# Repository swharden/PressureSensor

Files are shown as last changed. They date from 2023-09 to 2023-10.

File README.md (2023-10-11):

# Digital Pressure Sensor

This project contains design files for a minimal complexity digital pressure sensor. It uses a [HX710](https://image.micros.com.pl/_dane_techniczne_auto/uphx710b%20smd.pdf) 24-bit ADC to read differential voltage across a Whetstone bridge pressure sensor, then an [AD64DD32](https://ww1.microchip.com/downloads/aemDocuments/documents/MCU08/ProductDocuments/DataSheets/AVR64DD32-28-Prelim-DataSheet-DS40002315B.pdf) applies signal filtering in software and outputs the result as an analog signal using its built-in DAC. Filtering in software allows filter settings and recording modes to be adjusted in real time or further modified using firmware updates. Pressure is displayed on a multiplexed 7-segment display driven directly by pins of the microcontroller. Display mode can be toggled between pressure value, wave period, or wave frequency.

### Version 1.0

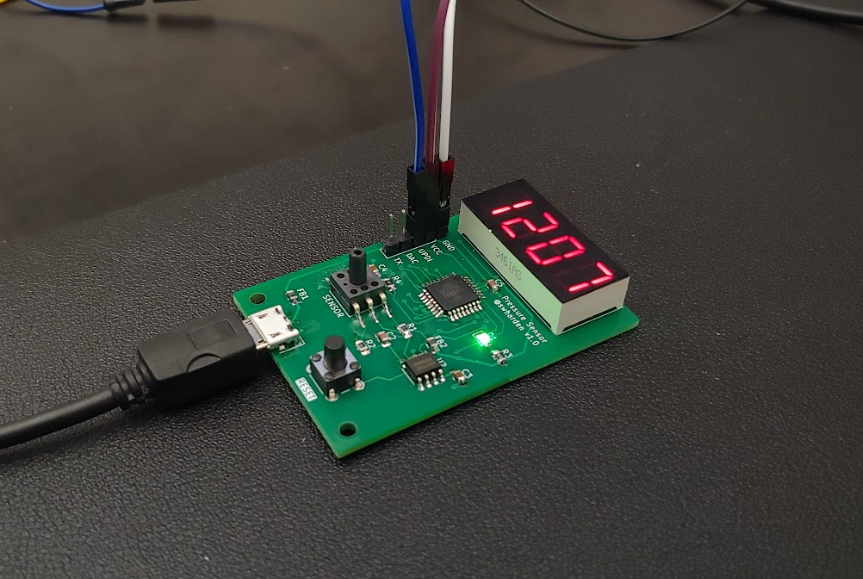
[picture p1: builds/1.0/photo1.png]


### Version 2.0

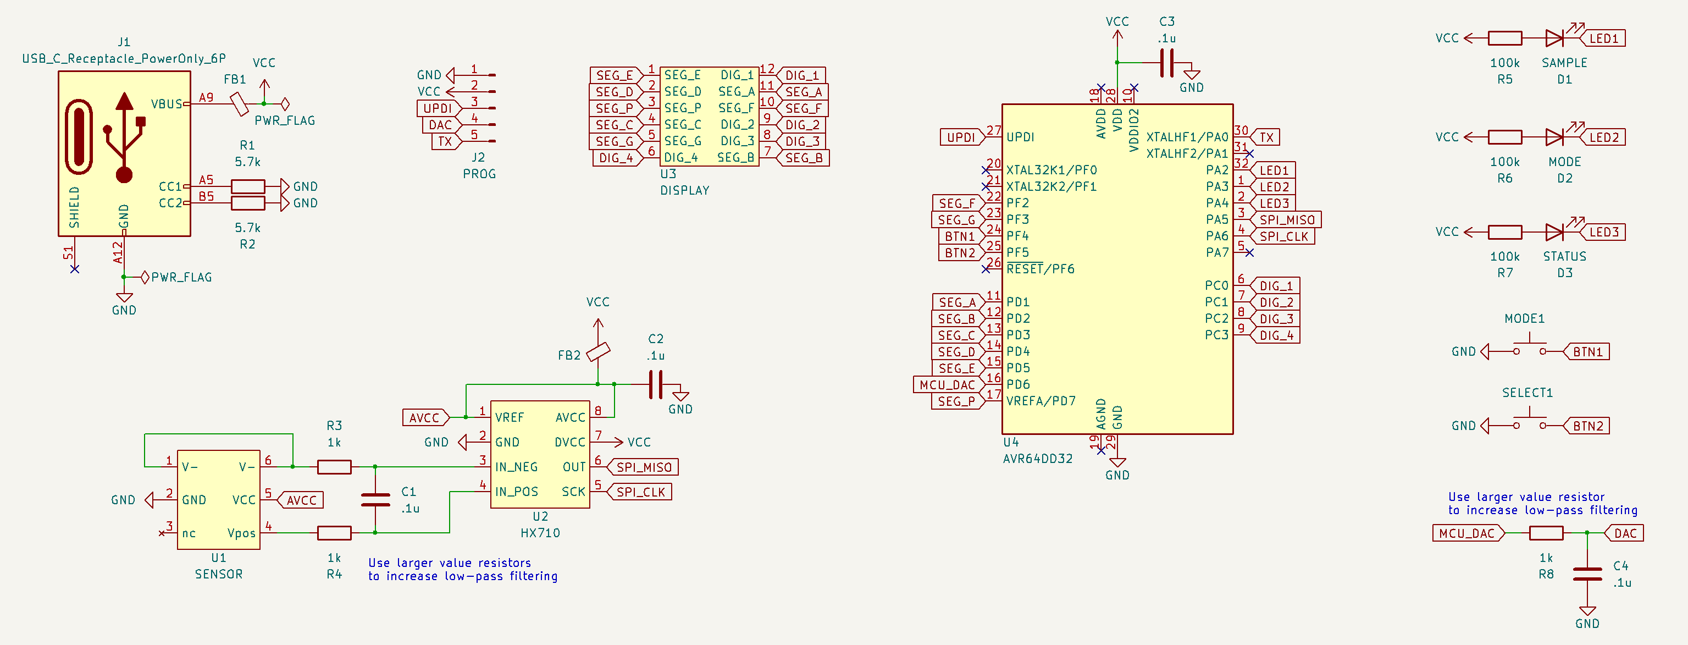
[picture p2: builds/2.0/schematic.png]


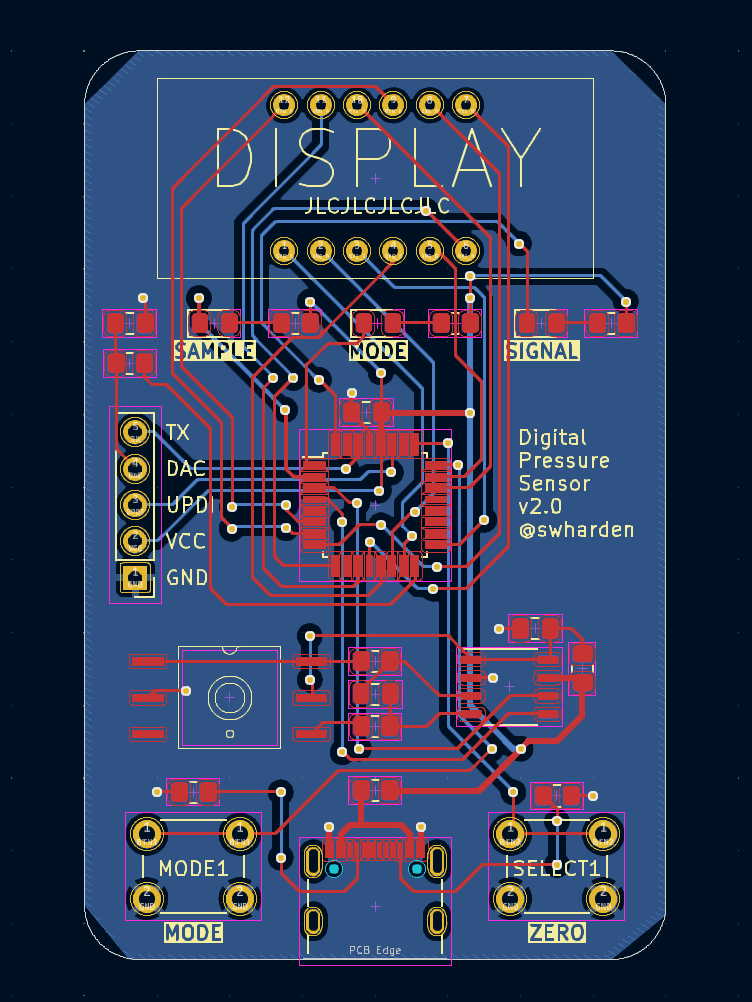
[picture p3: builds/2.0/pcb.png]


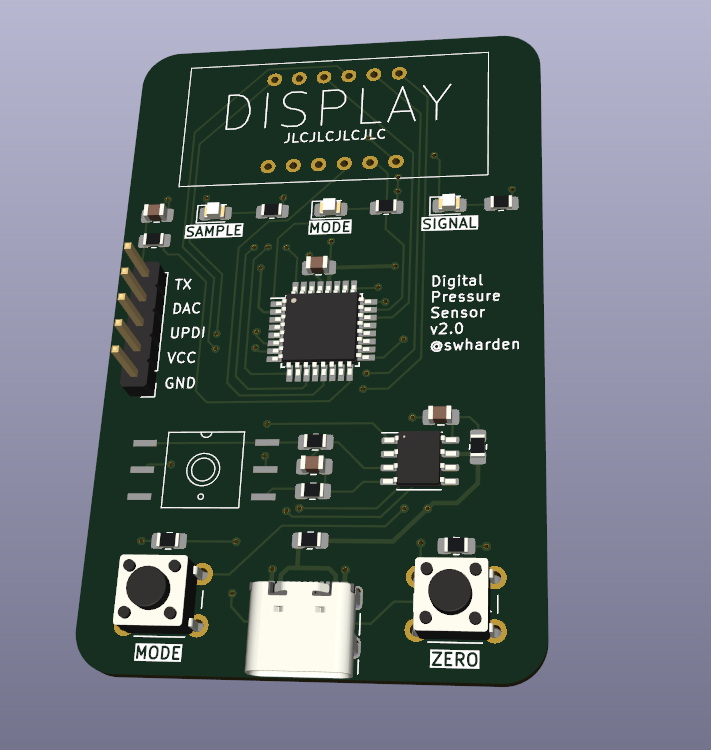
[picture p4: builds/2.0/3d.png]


#### Build Notes

* Through-hole buttons have leads out the bottom which fight against adhesive pads at the corners
* PCB near display could be notched to facilitate string or zip tie mounting vertically
* I'm unsure whether I like the USB connector on the bottom. The whole board could be turned upside down with the connector and buttons on the top.

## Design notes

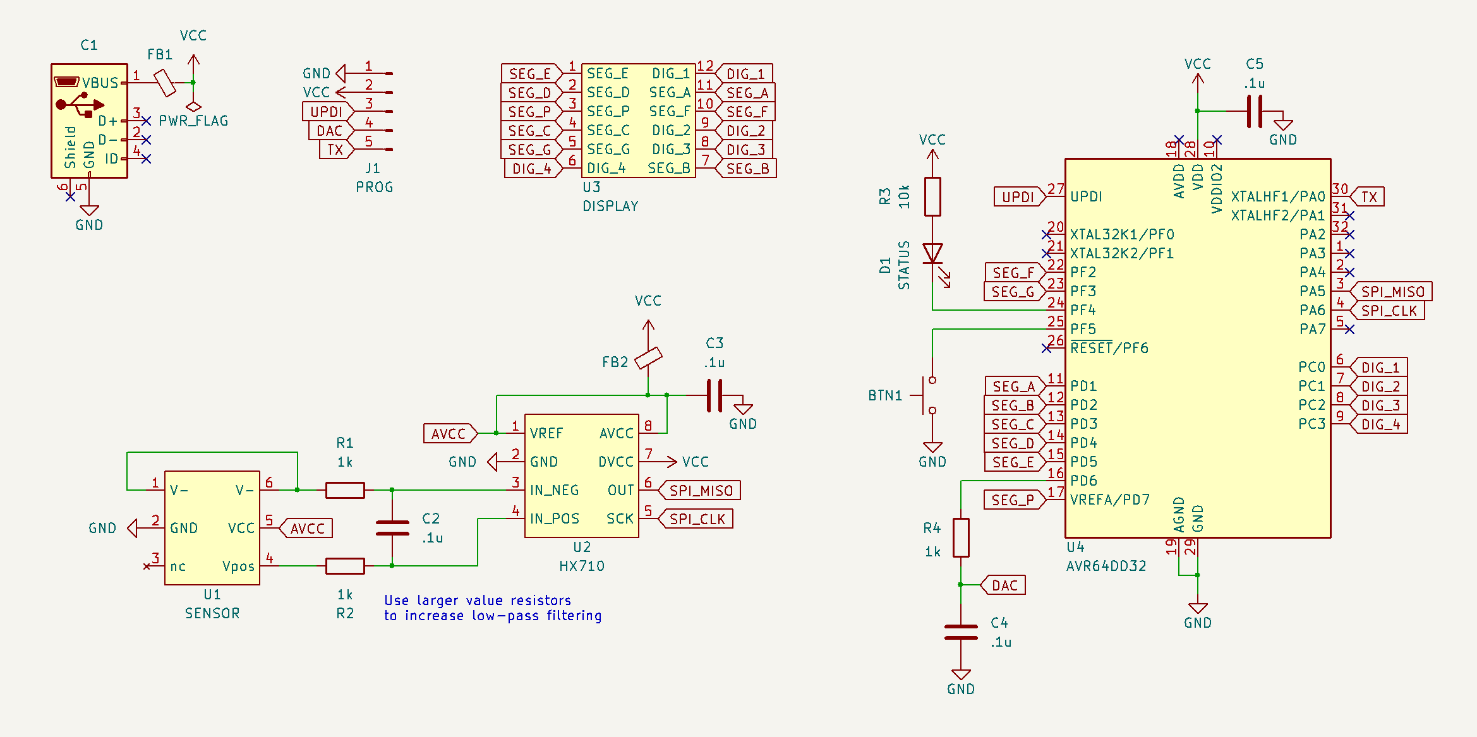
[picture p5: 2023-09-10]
builds/1.0/schematic.png

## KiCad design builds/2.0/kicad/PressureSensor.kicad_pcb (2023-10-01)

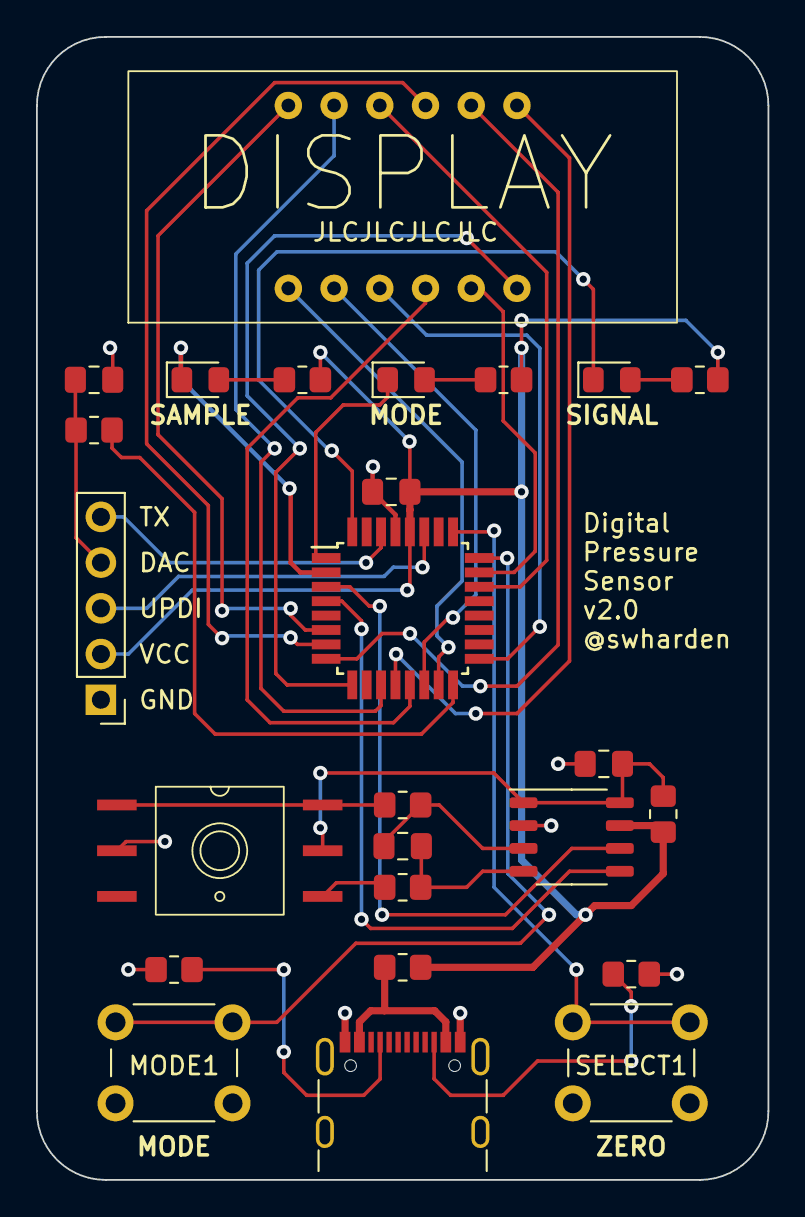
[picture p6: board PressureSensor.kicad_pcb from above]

Board: 2 copper layers, 40.6 x 63.5 mm, 25 parts (0 on the bottom side), 36 nets.

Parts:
C1, C2, C3, C4: .1u; C_0805_2012Metric_Pad1.18x1.45mm_HandSolder
D1: SAMPLE; LED_0805_2012Metric_Pad1.15x1.40mm_HandSolder
D2: MODE; LED_0805_2012Metric_Pad1.15x1.40mm_HandSolder
D3: STATUS; LED_0805_2012Metric_Pad1.15x1.40mm_HandSolder
FB1, FB2: FerriteBead_Small; R_0805_2012Metric_Pad1.20x1.40mm_HandSolder
J1: USB_C_Receptacle_PowerOnly_6P; USB_C_Receptacle_GCT_USB4105-xx-A_16P_TopMnt_Horizontal
J2: PROG; PinHeader_1x05_P2.54mm_Vertical
MODE1: SW_Push; SW_PUSH_6mm_H5mm
R1, R2: 5.7k; R_0805_2012Metric_Pad1.20x1.40mm_HandSolder
R3, R4, R8: 1k; R_0805_2012Metric_Pad1.20x1.40mm_HandSolder
R5, R6, R7: 100k; R_0805_2012Metric_Pad1.20x1.40mm_HandSolder
SELECT1: SW_Push; SW_PUSH_6mm_H5mm
U1: SENSOR; pressure-sensor-SOIC-6
U2: HX710; SSOP-8_3.9x5.05mm_P1.27mm
U3: DISPLAY; 7_seg_display_DIP12
U4: AVR64DD32; TQFP-32_7x7mm_P0.8mm

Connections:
AVCC: C2.1, FB2.1, U1.5 (VCC), U2.1 (VREF), U2.8 (AVCC)
BTN1: MODE1.1, U4.24 (PF4)
BTN2: SELECT1.1, U4.25 (PF5)
DAC: C4.1, J2.4, R8.1
DIG_1: U3.12 (DIG_1), U4.6 (PC0)
DIG_2: U3.9 (DIG_2), U4.7 (PC1)
DIG_3: U3.8 (DIG_3), U4.8 (PC2)
DIG_4: U3.6 (DIG_4), U4.9 (PC3)
GND: C2.2, C3.2, C4.2, J1.A1, J1.A12 (GND), J2.1, MODE1.2, R1.2, R2.1, SELECT1.2, U1.2 (GND), U2.2 (GND), U4.29 (GND)
LED1: D1.1 (K), U4.32 (PA2)
LED2: D2.1 (K), U4.1 (PA3)
LED3: D3.1 (K), U4.2 (PA4)
MCU_DAC: R8.2, U4.16 (PD6)
unnamed: D1.2 (A), R5.1
unnamed: D2.2 (A), R6.1
unnamed: D3.2 (A), R7.1
unnamed: FB1.1, J1.A4, J1.A9 (VBUS)
unnamed: J1.A5 (CC1), R1.1
unnamed: J1.B5 (CC2), R2.2
unnamed: R3.1, U1.1 (V-), U1.6 (V-)
unnamed: R4.2, U1.4 (Vpos)
unnamed: C1.1, R3.2, U2.3 (IN_NEG)
unnamed: C1.2, R4.1, U2.4 (IN_POS)
SEG_A: U3.11 (SEG_A), U4.11 (PD1)
SEG_B: U3.7 (SEG_B), U4.12 (PD2)
SEG_C: U3.4 (SEG_C), U4.13 (PD3)
SEG_D: U3.2 (SEG_D), U4.14 (PD4)
SEG_E: U3.1 (SEG_E), U4.15 (PD5)
SEG_F: U3.10 (SEG_F), U4.22 (PF2)
SEG_G: U3.5 (SEG_G), U4.23 (PF3)
SEG_P: U3.3 (SEG_P), U4.17 (VREFA/PD7)
SPI_CLK: U2.5 (SCK), U4.4 (PA6)
SPI_MISO: U2.6 (OUT), U4.3 (PA5)
TX: J2.5, U4.30 (XTALHF1/PA0)
UPDI: J2.3, U4.27 (UPDI)
VCC: C3.1, FB1.2, FB2.2, J2.2, R5.2, R6.2, R7.2, U2.7 (DVCC), U4.28 (VDD)

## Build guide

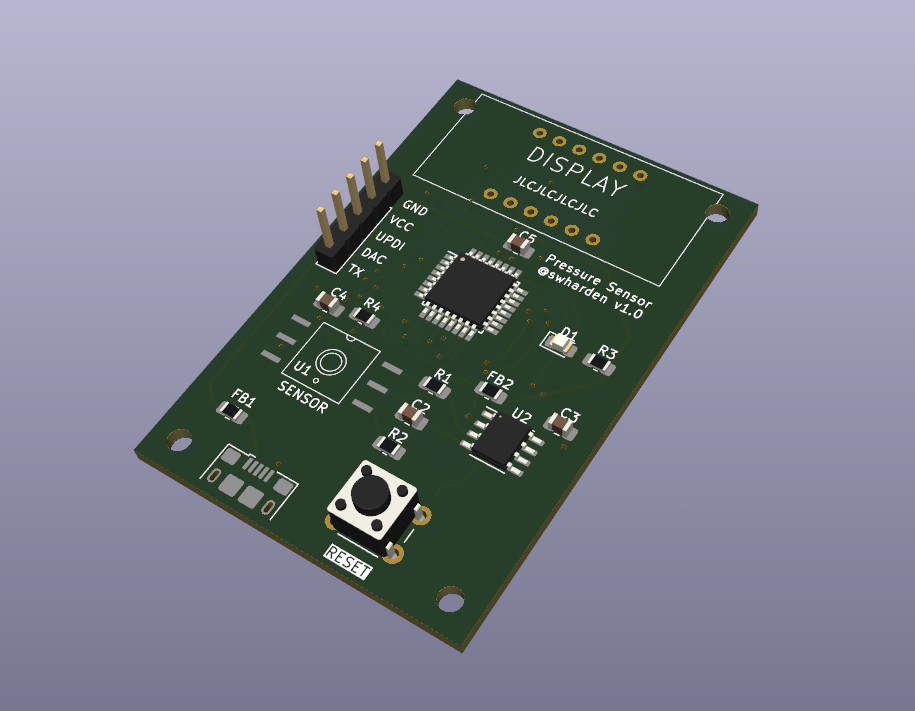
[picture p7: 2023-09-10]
builds/1.0/3d.png

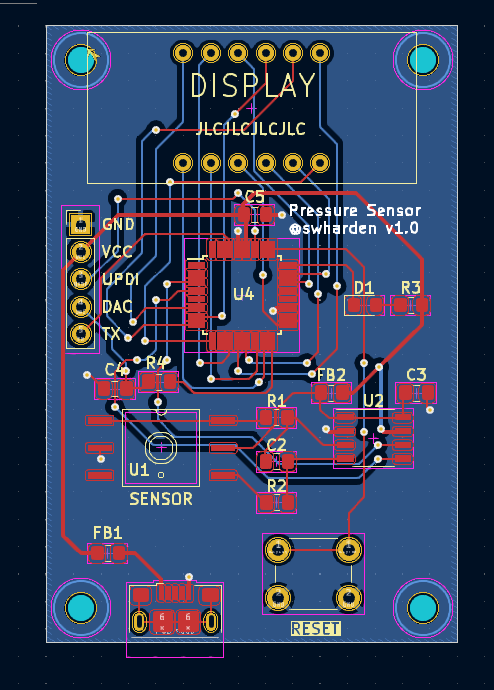
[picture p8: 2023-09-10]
builds/1.0/pcb.png

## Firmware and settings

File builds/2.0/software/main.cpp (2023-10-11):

#define F_CPU 4000000UL
#include <avr/io.h>
#include <util/delay.h>
#include <avr/interrupt.h>
#include "LedManager.h"
#include "DisplayManager.h"
#include "SerialManager.h"
#include "PressureSensor.h"
#include "ButtonManager.h"

LedManager leds = LedManager();
DisplayManager display = DisplayManager();
PressureSensor sensor = PressureSensor();
ButtonManager button = ButtonManager();

void setup_multiplex_display_timer(){
	TCB0.INTCTRL |= TCB_CAPT_bm;
	TCB0.CCMP = F_CPU / 500;
	TCB0.CTRLA |= TCB_ENABLE_bm;
	sei();
}

ISR(TCB0_INT_vect)
{
	display.multiplex_tick();
	TCB0.INTFLAGS = TCB_OVF_bm | TCB_CAPT_bm;
}

volatile int32_t zero_value = 0;

int main(void)
{
	leds.setup();
	display.setup();
	sensor.setup();
	button.setup();
	
	setup_multiplex_display_timer();

	// zero on startup
	// TODO: put this logic in the sensor manager
	for (int i=0; i<5; i++){
		zero_value = sensor.Read();
	}
	
	while(1){
		
		// TODO: put this logic in the sensor manager
		//leds.sample_toggle(); // NOTE: this is highly distracting if it's bright green
		int32_t sensor_value_raw = sensor.Read();
		int32_t sensor_value_centered = sensor_value_raw - zero_value;
		int16_t display_value = sensor_value_centered / 10000;
		display.show(display_value);
		
		if (button.is_down()){
			zero_value = sensor_value_raw;
			leds.mode_on();
			button.wait_until_up();
			leds.mode_off();
		}
	}
}

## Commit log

2023-09-07 start pcb
    [PressureSensor.kicad_pcb, PressureSensor.kicad_sch]
2023-09-10 pressure sensor footprint
    [PressureSensor.kicad_pcb, PressureSensor.kicad_sch]
2023-09-10 custom footprints
    [PressureSensor.kicad_pcb, PressureSensor.kicad_sch]
2023-09-10 schematic: improve filtering
    [PressureSensor.kicad_sch]
2023-09-10 schematic: all major components
    [PressureSensor.kicad_sch]
2023-09-10 improve HX710 symbol
    [PressureSensor.kicad_sch]
2023-09-10 update PCB layout
    [PressureSensor.kicad_pcb, PressureSensor.kicad_sch]
2023-09-10 kicad/ → builds/1.0/
    [PressureSensor.kicad_pcb, PressureSensor.kicad_sch]
2023-09-10 update gerbers
    move drill holes under display
    [PressureSensor.kicad_pcb]
2023-09-20 fix startup LED state
2023-09-22 2.0: new schematic
    [PressureSensor.kicad_pcb, PressureSensor.kicad_sch]
2023-09-30 update libraries
    [PressureSensor.kicad_pcb, PressureSensor.kicad_sch]
2023-09-30 layout PCB
    [PressureSensor.kicad_pcb]
2023-10-01 update PCB
    [PressureSensor.kicad_pcb]
2023-10-11 2.0 software: invert screen
    [main.cpp]
